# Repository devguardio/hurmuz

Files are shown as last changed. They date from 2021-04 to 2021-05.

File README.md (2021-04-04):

# Hürmüz - an rpi cm4 server board

Hürmüz is a devguard slice server board using the raspberry pi compute module 4 as CPU.

Ethernet is bundled via a KSZ9477 ethernet switch, where each CPU gets its own VLAN.
For recovery and management, USB is connected via an usb switch to an additional managment CPU.

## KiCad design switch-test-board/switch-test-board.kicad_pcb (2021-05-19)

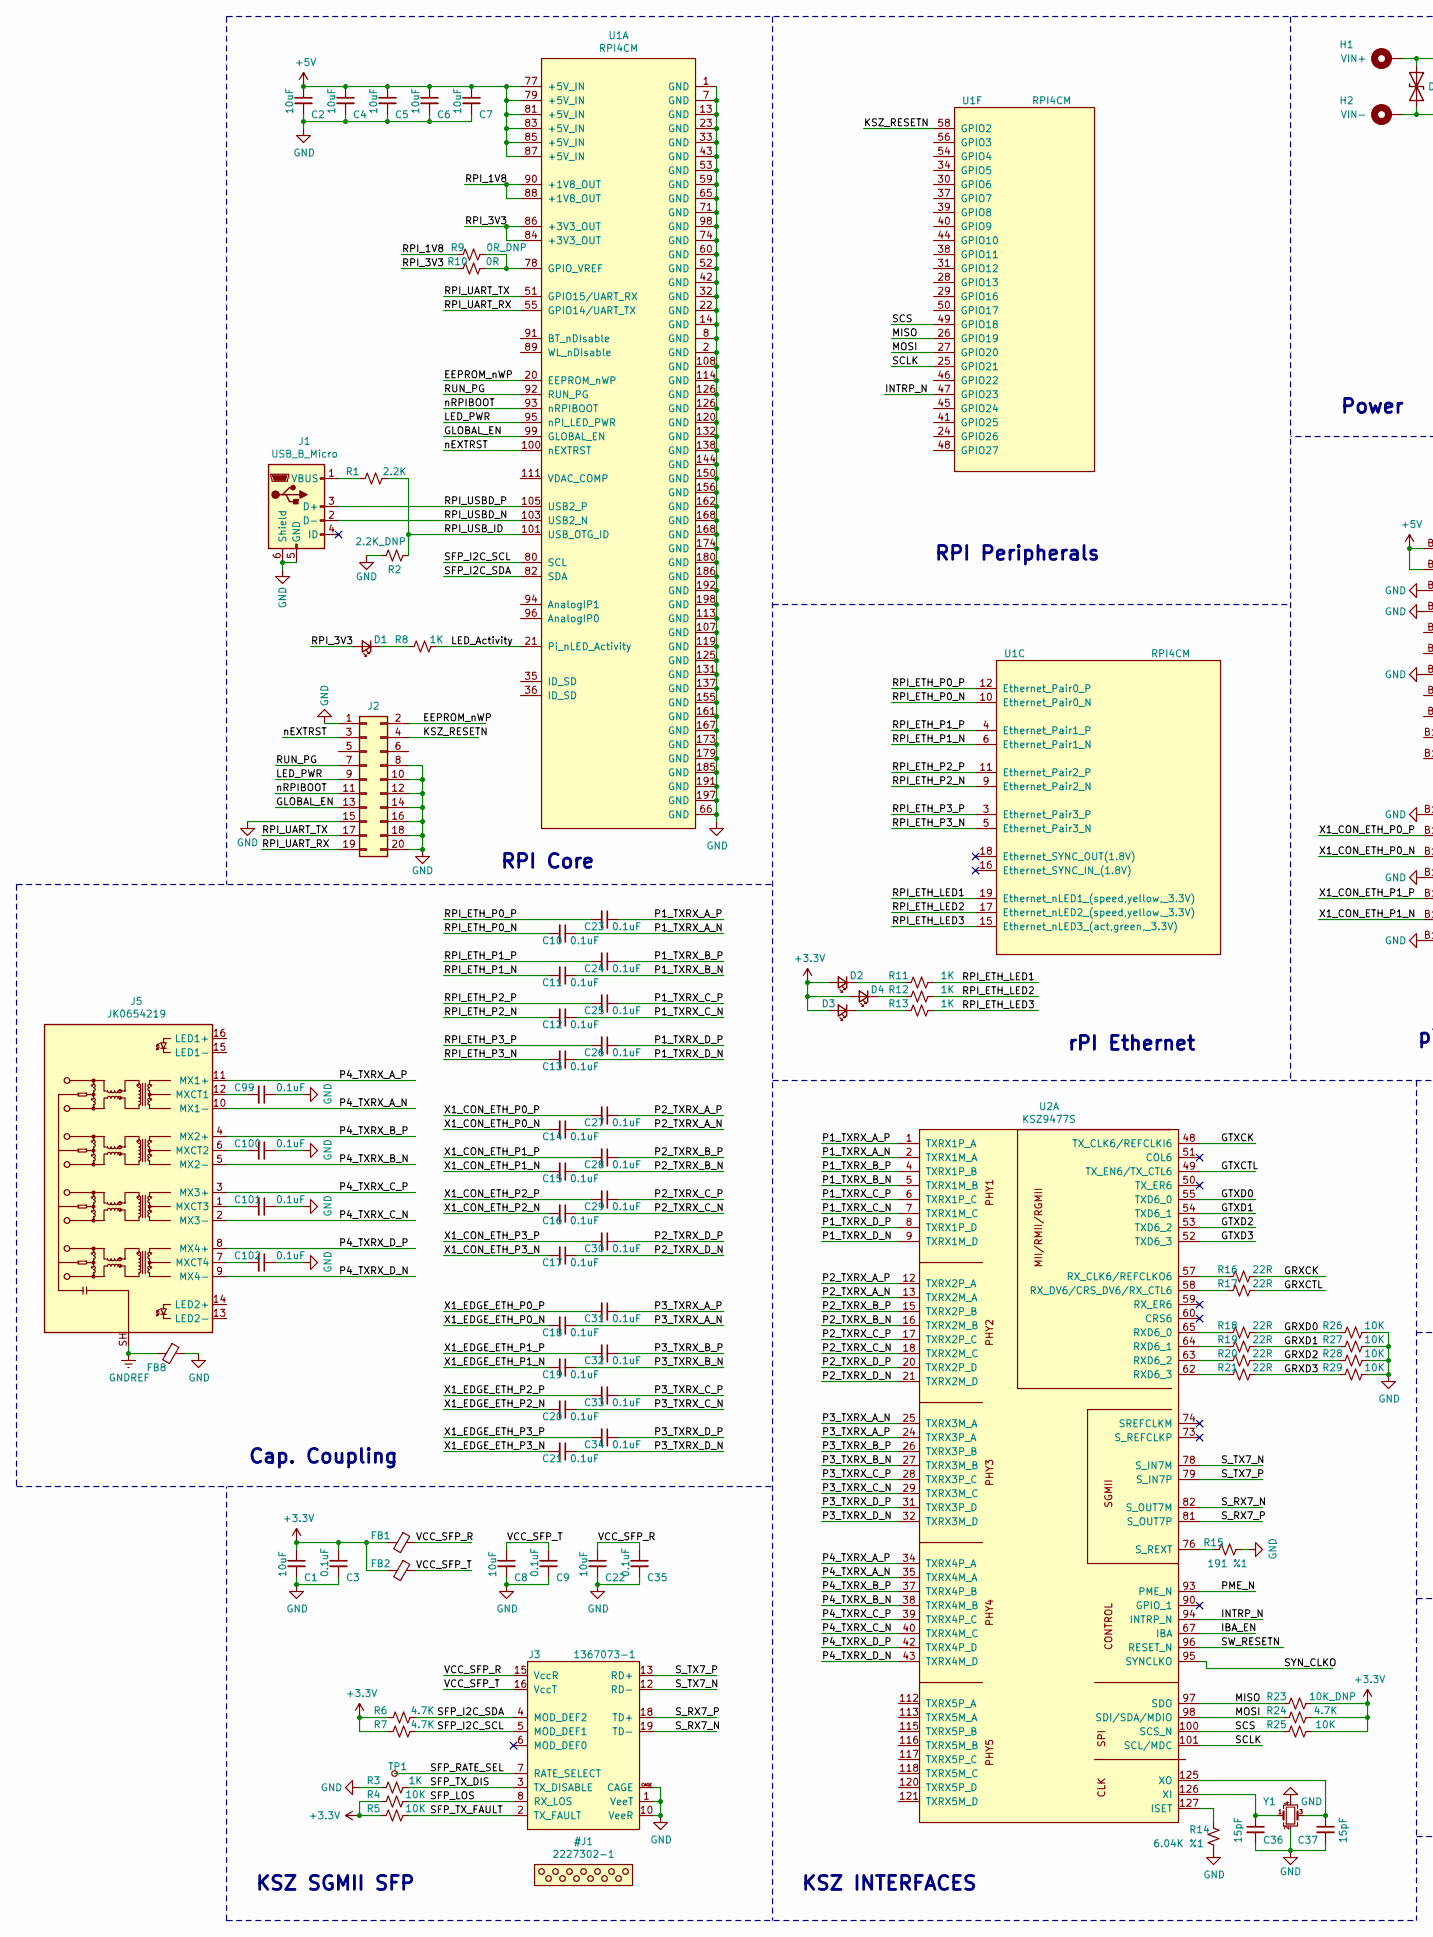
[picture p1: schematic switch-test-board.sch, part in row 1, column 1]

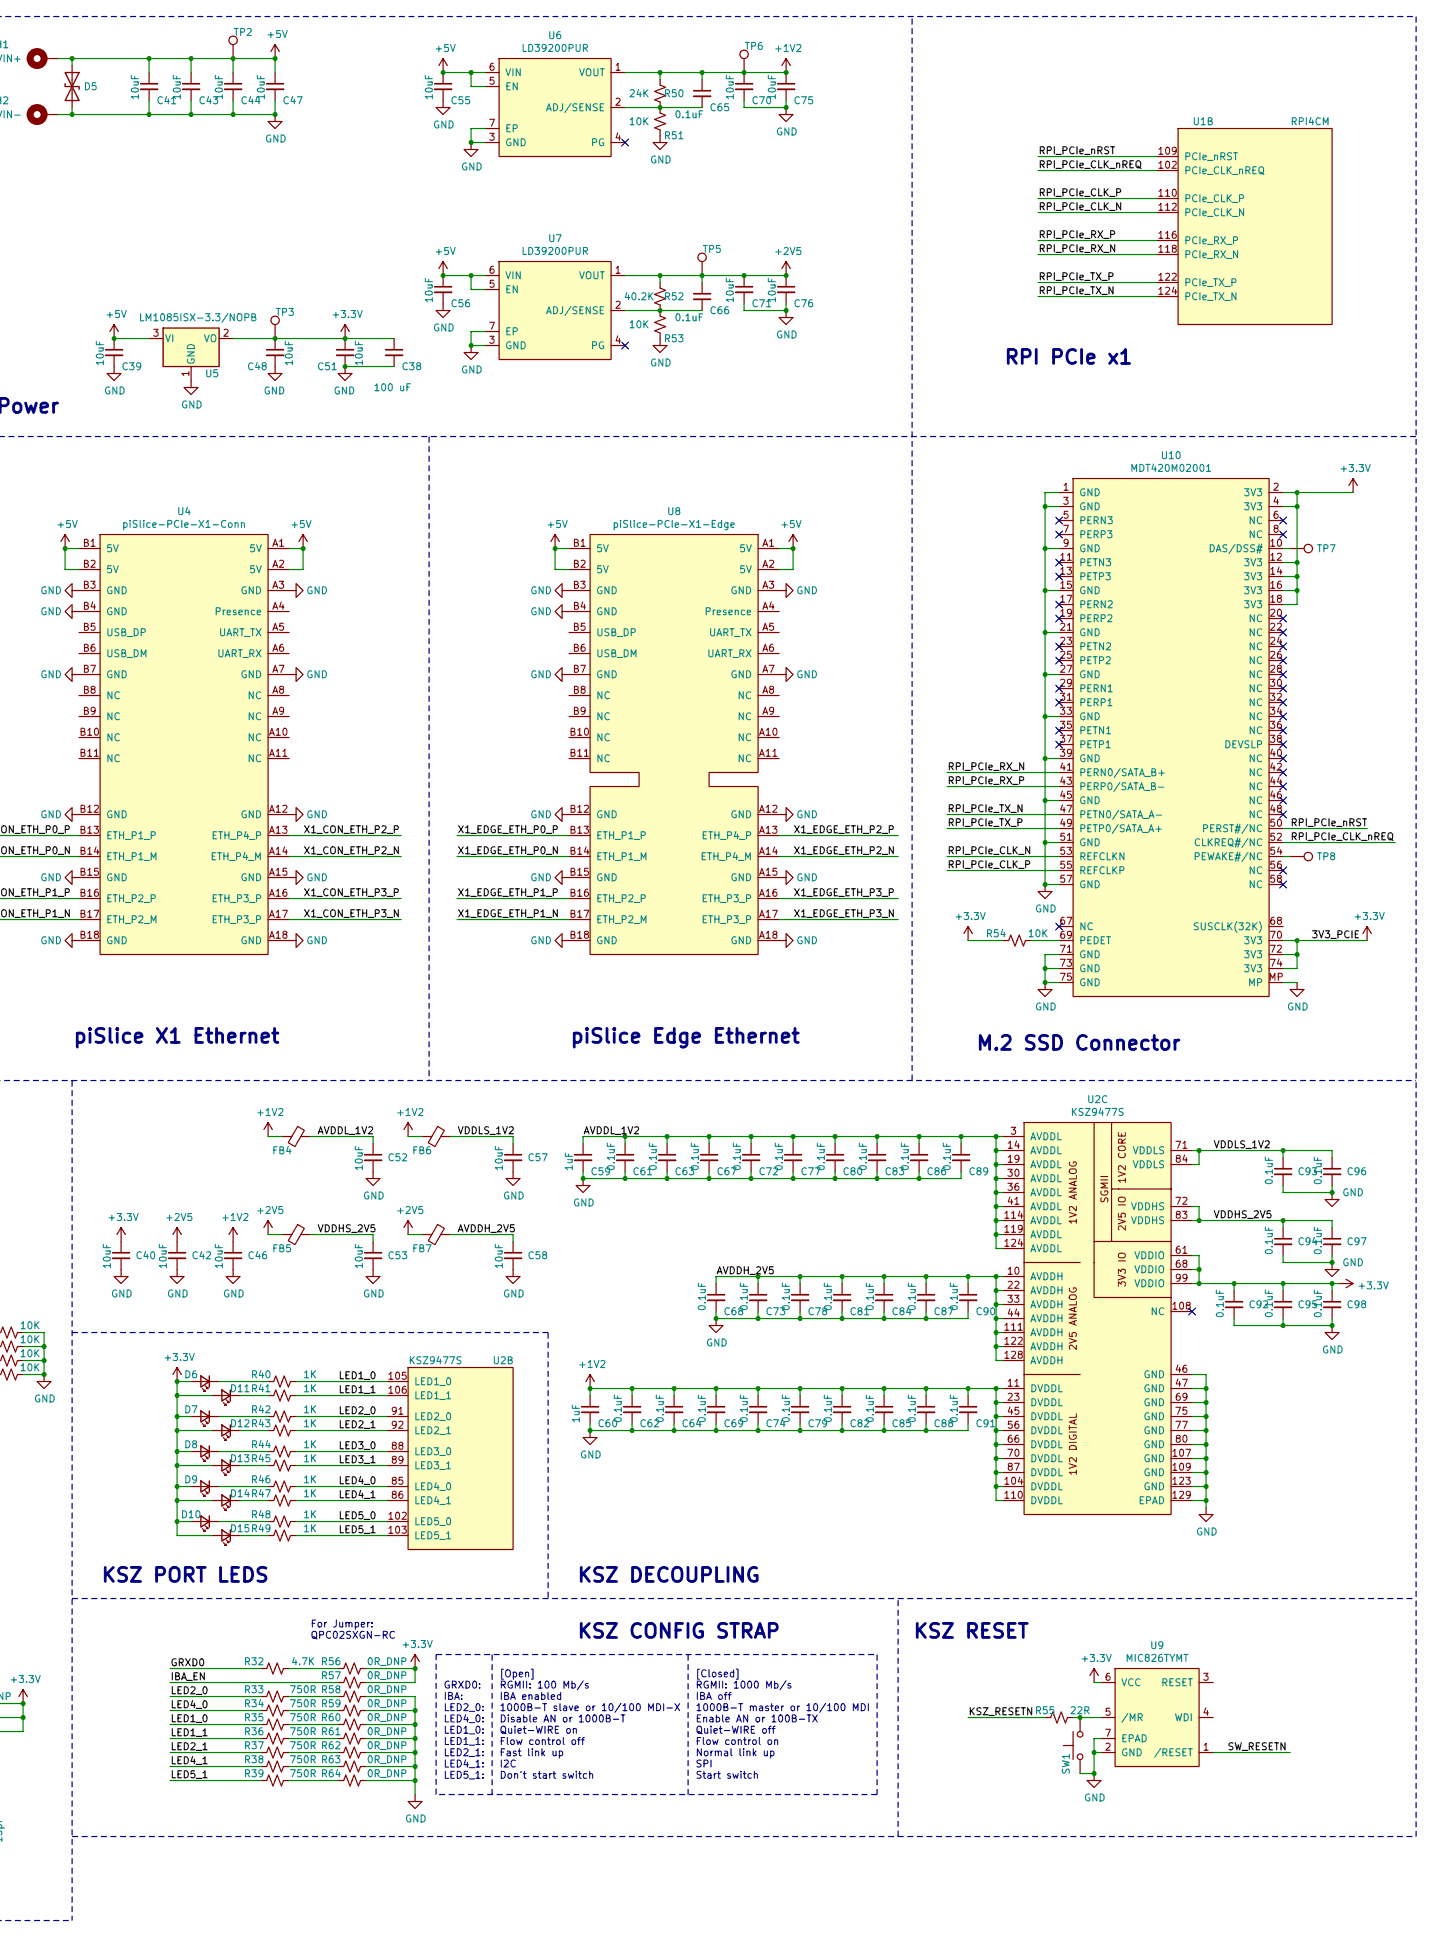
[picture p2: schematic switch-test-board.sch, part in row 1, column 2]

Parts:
C1, C2, C4, C5, C6, C7, C8, C22, C39, C40, C41, C42, C43, C44, C46, C47, C48, C51, C52, C53, C55, C56, C57, C58, C70, C71, C75, C76: 10uF; C_0603_1608Metric
C3, C9, C10, C11, C12, C13, C14, C15, C16, C17, C18, C19, C20, C21, C23, C24, C25, C26, C27, C28, C29, C30, C31, C32, C33, C34, C35, C61, C62, C63, C64, C65, C66, C67, C68, C69, C72, C73, C74, C77, C78, C79, C80, C81, C82, C83, C84, C85, C86, C87, C88, C89, C90, C91, C92, C93, C94, C95, C96, C97, C98, C99, C100, C101, C102: 0.1uF; C_0402_1005Metric
C36, C37: 15pF; C_0402_1005Metric
C38: 100 uF; CP_Elec_5x5.3; Part Number 865080142007
C59, C60: 1uF; C_0402_1005Metric
D1, D2, D4, D11, D12, D13, D14, D15: 150060RS75000; LED_0603_1608Metric
D3, D6, D7, D8, D9, D10: 150060GS75000; LED_0603_1608Metric
D5: SMAJ5.0CA-TR; D_SMA
FB1, FB2, FB4, FB5, FB6, FB7, FB8: BLM18EG221SN1D; ferrite-blm18
H1: VIN+; MountingHole_3.2mm_M3_Pad
H2: VIN-; MountingHole_3.2mm_M3_Pad
J1: USB_B_Micro; USB_Micro-B_GCT_USB3076-30-A
J2: 2011-2X10G00SD025B; PinHeader_2x10_P2.54mm_Vertical
J3: 1367073-1; SFP_with_Cage
J5: JK0654219; RJ45_Pulse_JK0654219NL_Horizontal
R1: 2.2K; R_0402_1005Metric
R2: 2.2K_DNP; R_0402_1005Metric
R3, R8, R11, R12, R13, R40, R41, R42, R43, R44, R45, R46, R47, R48, R49: 1K; R_0402_1005Metric
R4, R5, R25, R26, R27, R28, R29, R51, R53, R54: 10K; R_0402_1005Metric
R6, R7, R24, R32: 4.7K; R_0402_1005Metric
R9, R56, R57, R58, R59, R60, R61, R62, R63, R64: 0R_DNP; R_0402_1005Metric
R10: 0R; R_0402_1005Metric
R14: 6.04K %1; R_0402_1005Metric
R15: 191 %1; R_0402_1005Metric
R16, R17, R18, R19, R20, R21, R55: 22R; R_0402_1005Metric
R23: 10K_DNP; R_0402_1005Metric
R33, R34, R35, R36, R37, R38, R39: 750R; R_0402_1005Metric
R50: 24K; R_0402_1005Metric
R52: 40.2K; R_0402_1005Metric
SW1: PTS645SM43SMTR92 LFS; SW_SPST_PTS645
TP1: TestPoint_Small; TestPoint_Pad_D1.0mm
TP2, TP3, TP5, TP6, TP7, TP8: TestPoint; TestPoint_Pad_D1.0mm
U1: RPI4CM; rpi-cm4
U2: KSZ9477S; 128-TQFP-EP
U4: piSlice-PCIe-X1-Conn; 10018783-10200TLF
U5: LM1085ISX-3.3/NOPB; TO-263-3_TabPin2
U6, U7: LD39200PUR; DFN-6-1EP_3x3mm_P0.95mm_EP1.7x2.6mm
U8: piSlice-PCIe-X1-Edge; piSlice_PCIexpress_x1
U9: MIC826TYMT; MLF-6-1EP_1.6x1.6mm_P0.5mm_EP0.5x1.26mm
U10: MDT420M02001; M.2_Amphenol_MDT_2280
Y1: ABM8G-25.000MHZ-B4Y-T; Crystal_SMD_Abracon_ABM8G-4Pin_3.2x2.5mm

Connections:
+1V2: C46.1, C60.1, C62.1, C64.1, C65.1, C69.1, C70.1, C74.1, C75.1, C79.1, C82.1, C85.1, C88.1, C91.1, FB4.2, FB6.2, R50.2, TP6.1, U2.11 (DVDDL), U2.23 (DVDDL), U2.45 (DVDDL), U2.56 (DVDDL), U2.66 (DVDDL), U2.70 (DVDDL), U2.87 (DVDDL), U2.104 (DVDDL), U2.110 (DVDDL), U6.1 (VOUT)
+2V5: C42.1, C66.1, C71.1, C76.1, FB5.2, FB7.2, R52.2, TP5.1, U7.1 (VOUT)
+3V3: C1.1, C3.1, C38.1, C40.1, C48.1, C51.1, C92.1, C95.1, C98.1, D2.2 (A), D3.2 (A), D4.2 (A), D6.2 (A), D7.2 (A), D8.2 (A), D9.2 (A), D10.2 (A), D11.2 (A), D12.2 (A), D13.2 (A), D14.2 (A), D15.2 (A), FB1.2, FB2.2, R4.1, R5.1, R6.1, R7.1, R23.1, R24.1, R25.1, R54.1, R56.1, R57.1, TP3.1, U2.61 (VDDIO), U2.68 (VDDIO), U2.99 (VDDIO), U5.2 (VO), U9.6 (VCC), U10.2 (3V3), U10.4 (3V3), U10.12 (3V3), U10.14 (3V3), U10.16 (3V3), U10.18 (3V3), U10.70 (3V3), U10.72 (3V3), U10.74 (3V3)
+5V: C2.1, C4.1, C5.1, C6.1, C7.1, C39.1, C41.1, C43.1, C44.1, C47.1, C55.1, C56.1, D5.1 (A1), H1.1, TP2.1, U1.77 (+5V_IN), U1.79 (+5V_IN), U1.81 (+5V_IN), U1.83 (+5V_IN), U1.85 (+5V_IN), U1.87 (+5V_IN), U4.A1 (5V), U4.A2 (5V), U4.B1 (5V), U4.B2 (5V), U5.3 (VI), U6.5 (EN), U6.6 (VIN), U7.5 (EN), U7.6 (VIN), U8.A1 (5V), U8.A2 (5V), U8.B1 (5V), U8.B2 (5V)
/AVDDH_2V5: C58.1, C68.1, C73.1, C78.1, C81.1, C84.1, C87.1, C90.1, FB7.1, U2.10 (AVDDH), U2.22 (AVDDH), U2.33 (AVDDH), U2.44 (AVDDH), U2.111 (AVDDH), U2.122 (AVDDH), U2.128 (AVDDH)
/AVDDL_1V2: C52.1, C59.1, C61.1, C63.1, C67.1, C72.1, C77.1, C80.1, C83.1, C86.1, C89.1, FB4.1, U2.3 (AVDDL), U2.14 (AVDDL), U2.19 (AVDDL), U2.30 (AVDDL), U2.36 (AVDDL), U2.41 (AVDDL), U2.114 (AVDDL), U2.119 (AVDDL), U2.124 (AVDDL)
/EEPROM_nWP: J2.2, U1.20 (EEPROM_nWP)
/GLOBAL_EN: J2.13, U1.99 (GLOBAL_EN)
/GRXCK: R16.2
/GRXCTL: R17.2
/GRXD0: R18.2, R26.1, R32.2
/GRXD1: R19.2, R27.1
/GRXD2: R20.2, R28.1
/GRXD3: R21.2, R29.1
/GTXCK: U2.48 (TX_CLK6/REFCLKI6)
/GTXCTL: U2.49 (TX_EN6/TX_CTL6)
/GTXD0: U2.55 (TXD6_0)
/GTXD1: U2.54 (TXD6_1)
/GTXD2: U2.53 (TXD6_2)
/GTXD3: U2.52 (TXD6_3)
/IBA_EN: R57.2, U2.67 (IBA)
/INTRP_N: U1.47 (GPIO23), U2.94 (INTRP_N)
/KSZ_RESETN: J2.4, R55.1, U1.58 (GPIO2)
/LED1_0: R35.2, R40.1, U2.105 (LED1_0)
/LED1_1: R36.2, R41.1, U2.106 (LED1_1)
/LED2_0: R33.2, R42.1, U2.91 (LED2_0)
/LED2_1: R37.2, R43.1, U2.92 (LED2_1)
/LED3_0: R44.1, U2.88 (LED3_0)
/LED3_1: R45.1, U2.89 (LED3_1)
/LED4_0: R34.2, R46.1, U2.85 (LED4_0)
/LED4_1: R38.2, R47.1, U2.86 (LED4_1)
/LED5_0: R48.1, U2.102 (LED5_0)
/LED5_1: R39.2, R49.1, U2.103 (LED5_1)
/LED_Activity: R8.1, U1.21 (Pi_nLED_Activity)
/LED_PWR: J2.9, U1.95 (nPI_LED_PWR)
/MISO: R23.2, U1.26 (GPIO19), U2.97 (SDO)
/MOSI: R24.2, U1.27 (GPIO20), U2.98 (SDI/SDA/MDIO)
/P1_TXRX_A_N: C10.1, U2.2 (TXRX1M_A)
/P1_TXRX_A_P: C23.1, U2.1 (TXRX1P_A)
/P1_TXRX_B_N: C11.1, U2.5 (TXRX1M_B)
/P1_TXRX_B_P: C24.1, U2.4 (TXRX1P_B)
/P1_TXRX_C_N: C12.1, U2.7 (TXRX1M_C)
/P1_TXRX_C_P: C25.1, U2.6 (TXRX1P_C)
/P1_TXRX_D_N: C13.1, U2.9 (TXRX1M_D)
/P1_TXRX_D_P: C26.1, U2.8 (TXRX1P_D)
/P2_TXRX_A_N: C14.1, U2.13 (TXRX2M_A)
/P2_TXRX_A_P: C27.1, U2.12 (TXRX2P_A)
/P2_TXRX_B_N: C15.1, U2.16 (TXRX2M_B)
/P2_TXRX_B_P: C28.1, U2.15 (TXRX2P_B)
/P2_TXRX_C_N: C16.1, U2.18 (TXRX2M_C)
/P2_TXRX_C_P: C29.1, U2.17 (TXRX2P_C)
/P2_TXRX_D_N: C17.1, U2.21 (TXRX2M_D)
/P2_TXRX_D_P: C30.1, U2.20 (TXRX2P_D)
/P3_TXRX_A_N: C18.1, U2.25 (TXRX3M_A)
/P3_TXRX_A_P: C31.1, U2.24 (TXRX3P_A)
/P3_TXRX_B_N: C19.1, U2.27 (TXRX3M_B)
/P3_TXRX_B_P: C32.1, U2.26 (TXRX3P_B)
/P3_TXRX_C_N: C20.1, U2.29 (TXRX3M_C)
/P3_TXRX_C_P: C33.1, U2.28 (TXRX3P_C)
/P3_TXRX_D_N: C21.1, U2.32 (TXRX3M_D)
/P3_TXRX_D_P: C34.1, U2.31 (TXRX3P_D)
/P4_TXRX_A_N: J5.10 (MX1-), U2.35 (TXRX4M_A)
/P4_TXRX_A_P: J5.11 (MX1+), U2.34 (TXRX4P_A)
/P4_TXRX_B_N: J5.5 (MX2-), U2.38 (TXRX4M_B)
/P4_TXRX_B_P: J5.4 (MX2+), U2.37 (TXRX4P_B)
/P4_TXRX_C_N: J5.2 (MX3-), U2.40 (TXRX4M_C)
/P4_TXRX_C_P: J5.3 (MX3+), U2.39 (TXRX4P_C)
/P4_TXRX_D_N: J5.9 (MX4-), U2.43 (TXRX4M_D)
/P4_TXRX_D_P: J5.8 (MX4+), U2.42 (TXRX4P_D)
/PME_N: U2.93 (PME_N)
/RPI_1V8: R9.1, U1.88 (+1V8_OUT), U1.90 (+1V8_OUT)
/RPI_3V3: D1.2 (A), R10.1, U1.84 (+3V3_OUT), U1.86 (+3V3_OUT)
/RPI_ETH_LED1: R11.1, U1.19 (Ethernet_nLED1_(speed,yellow,_3.3V))
/RPI_ETH_LED2: R12.1, U1.17 (Ethernet_nLED2_(speed,yellow,_3.3V))
/RPI_ETH_LED3: R13.1, U1.15 (Ethernet_nLED3_(act,green,_3.3V))
/RPI_ETH_P0_N: C10.2, U1.10 (Ethernet_Pair0_N)
/RPI_ETH_P0_P: C23.2, U1.12 (Ethernet_Pair0_P)
/RPI_ETH_P1_N: C11.2, U1.6 (Ethernet_Pair1_N)
/RPI_ETH_P1_P: C24.2, U1.4 (Ethernet_Pair1_P)
/RPI_ETH_P2_N: C12.2, U1.9 (Ethernet_Pair2_N)
/RPI_ETH_P2_P: C25.2, U1.11 (Ethernet_Pair2_P)
/RPI_ETH_P3_N: C13.2, U1.5 (Ethernet_Pair3_N)
/RPI_ETH_P3_P: C26.2, U1.3 (Ethernet_Pair3_P)
/RPI_PCIe_CLK_N: U1.112 (PCIe_CLK_N), U10.53 (REFCLKN)
/RPI_PCIe_CLK_P: U1.110 (PCIe_CLK_P), U10.55 (REFCLKP)
/RPI_PCIe_CLK_nREQ: U1.102 (PCIe_CLK_nREQ), U10.52 (CLKREQ#/NC)
/RPI_PCIe_RX_N: U1.118 (PCIe_RX_N), U10.41 (PERN0/SATA_B+)
/RPI_PCIe_RX_P: U1.116 (PCIe_RX_P), U10.43 (PERP0/SATA_B-)
/RPI_PCIe_TX_N: U1.124 (PCIe_TX_N), U10.47 (PETN0/SATA_A-)
/RPI_PCIe_TX_P: U1.122 (PCIe_TX_P), U10.49 (PETP0/SATA_A+)
/RPI_PCIe_nRST: U1.109 (PCIe_nRST), U10.50 (PERST#/NC)
/RPI_UART_RX: J2.19, U1.55 (GPIO14/UART_TX)
/RPI_UART_TX: J2.17, U1.51 (GPIO15/UART_RX)
/RPI_USBD_N: J1.2 (D-), U1.103 (USB2_N)
/RPI_USBD_P: J1.3 (D+), U1.105 (USB2_P)
/RPI_USB_ID: R1.1, R2.2, U1.101 (USB_OTG_ID)
/RUN_PG: J2.7, U1.92 (RUN_PG)
/SCLK: U1.25 (GPIO21), U2.101 (SCL/MDC)
/SCS: R25.2, U1.49 (GPIO18), U2.100 (SCS_N)
/SFP_I2C_SCL: J3.5 (MOD_DEF1), R7.2, U1.80 (SCL)
/SFP_I2C_SDA: J3.4 (MOD_DEF2), R6.2, U1.82 (SDA)
/SFP_LOS: J3.8 (RX_LOS), R4.2
/SFP_RATE_SEL: J3.7 (RATE_SELECT), TP1.1
/SFP_TX_DIS: J3.3 (TX_DISABLE), R3.2
/SFP_TX_FAULT: J3.2 (TX_FAULT), R5.2
/SW_RESETN: U2.96 (RESET_N), U9.1 (/RESET)
/SYN_CLKO: U2.95 (SYNCLKO)
/S_RX7_N: J3.19 (TD-), U2.82 (S_OUT7M)
/S_RX7_P: J3.18 (TD+), U2.81 (S_OUT7P)
/S_TX7_N: J3.12 (RD-), U2.78 (S_IN7M)
/S_TX7_P: J3.13 (RD+), U2.79 (S_IN7P)
/VCC_SFP_R: C22.1, C35.1, FB1.1, J3.15 (VccR)
/VCC_SFP_T: C8.1, C9.1, FB2.1, J3.16 (VccT)
/VDDHS_2V5: C53.1, C94.1, C97.1, FB5.1, U2.72 (VDDHS), U2.83 (VDDHS)
/VDDLS_1V2: C57.1, C93.1, C96.1, FB6.1, U2.71 (VDDLS), U2.84 (VDDLS)
/X1_CON_ETH_P0_N: C14.2, U4.B14 (ETH_P1_M)
/X1_CON_ETH_P0_P: C27.2, U4.B13 (ETH_P1_P)
/X1_CON_ETH_P1_N: C15.2, U4.B17 (ETH_P2_M)
/X1_CON_ETH_P1_P: C28.2, U4.B16 (ETH_P2_P)
/X1_CON_ETH_P2_N: C16.2, U4.A14 (ETH_P4_M)
/X1_CON_ETH_P2_P: C29.2, U4.A13 (ETH_P4_P)
/X1_CON_ETH_P3_N: C17.2, U4.A17 (ETH_P3_P)
/X1_CON_ETH_P3_P: C30.2, U4.A16 (ETH_P3_P)
/X1_EDGE_ETH_P0_N: C18.2, U8.B14 (ETH_P1_M)
/X1_EDGE_ETH_P0_P: C31.2, U8.B13 (ETH_P1_P)
/X1_EDGE_ETH_P1_N: C19.2, U8.B17 (ETH_P2_M)
/X1_EDGE_ETH_P1_P: C32.2, U8.B16 (ETH_P2_P)
/X1_EDGE_ETH_P2_N: C20.2, U8.A14 (ETH_P4_M)
/X1_EDGE_ETH_P2_P: C33.2, U8.A13 (ETH_P4_P)
/X1_EDGE_ETH_P3_N: C21.2, U8.A17 (ETH_P3_P)
/X1_EDGE_ETH_P3_P: C34.2, U8.A16 (ETH_P3_P)
/nEXTRST: J2.3, U1.100 (nEXTRST)
/nRPIBOOT: J2.11, U1.93 (nRPIBOOT)
GND: C1.2, C2.2, C3.2, C4.2, C5.2, C6.2, C7.2, C8.2, C9.2, C22.2, C35.2, C36.2, C37.2, C38.2, C39.2, C40.2, C41.2, C42.2, C43.2, C44.2, C46.2, C47.2, C48.2, C51.2, C52.2, C53.2, C55.2, C56.2, C57.2, C58.2, C59.2, C60.2, C61.2, C62.2, C63.2, C64.2, C67.2, C68.2, C69.2, C70.2, C71.2, C72.2, C73.2, C74.2, C75.2, C76.2, C77.2, C78.2, C79.2, C80.2, C81.2, C82.2, C83.2, C84.2, C85.2, C86.2, C87.2, C88.2, C89.2, C90.2, C91.2, C92.2, C93.2, C94.2, C95.2, C96.2, C97.2, C98.2, C99.1, C100.1, C101.1, C102.1, D5.2 (A2), FB8.1, H2.1, J1.5 (GND), J1.6 (Shield), J2.1, J2.8, J2.10, J2.12, J2.14, J2.15, J2.16, J2.18, J2.20, J3.1 (VeeT), J3.9 (VeeR), J3.10 (VeeR), J3.11 (VeeR), J3.14 (VeeR), J3.17 (VeeT), J3.20 (VeeT), J3.CAGE, R2.1, R3.1, R14.1, R15.2, R26.2, R27.2, R28.2, R29.2, R51.1, R53.1, R58.1, R59.1, R60.1, R61.1, R62.1, R63.1, R64.1, SW1.1, U1.1 (GND), U1.2 (GND), U1.7 (GND), U1.8 (GND), U1.13 (GND), U1.14 (GND), U1.22 (GND), U1.23 (GND), U1.32 (GND), U1.33 (GND), U1.42 (GND), U1.43 (GND), U1.52 (GND), U1.53 (GND), U1.59 (GND), U1.60 (GND), U1.65 (GND), U1.66 (GND), U1.71 (GND), U1.74 (GND), U1.98 (GND), U1.107 (GND), U1.108 (GND), U1.113 (GND), U1.114 (GND), U1.119 (GND), U1.120 (GND), U1.125 (GND), U1.126 (GND), U1.131 (GND), U1.132 (GND), U1.137 (GND), U1.138 (GND), U1.144 (GND), U1.150 (GND), U1.155 (GND), U1.156 (GND), U1.161 (GND), U1.162 (GND), U1.167 (GND), U1.168 (GND), U1.173 (GND), U1.174 (GND), U1.179 (GND), U1.180 (GND), U1.185 (GND), U1.186 (GND), U1.191 (GND), U1.192 (GND), U1.197 (GND), U1.198 (GND), U2.46 (GND), U2.47 (GND), U2.69 (GND), U2.75 (GND), U2.77 (GND), U2.80 (GND), U2.107 (GND), U2.109 (GND), U2.123 (GND), U2.129 (EPAD), U4.A3 (GND), U4.A7 (GND), U4.A12 (GND), U4.A15 (GND), U4.A18 (GND), U4.B3 (GND), U4.B4 (GND), U4.B7 (GND), U4.B12 (GND), U4.B15 (GND), U4.B18 (GND), U5.1 (GND), U6.3 (GND), U6.7 (EP), U7.3 (GND), U7.7 (EP), U8.A3 (GND), U8.A7 (GND), U8.A12 (GND), U8.A15 (GND), U8.A18 (GND), U8.B3 (GND), U8.B4 (GND), U8.B7 (GND), U8.B12 (GND), U8.B15 (GND), U8.B18 (GND), U9.2 (GND), U9.7 (EPAD), U10.1 (GND), U10.3 (GND), U10.9 (GND), U10.15 (GND), U10.21 (GND), U10.27 (GND), U10.33 (GND), U10.39 (GND), U10.45 (GND), U10.51 (GND), U10.57 (GND), U10.71 (GND), U10.73 (GND), U10.75 (GND), U10.MP, Y1.2, Y1.4
GNDREF: FB8.2, J5.SH
unnamed: C36.1, U2.126 (XI), Y1.1
unnamed: C37.1, U2.125 (XO), Y1.3
unnamed: C65.2, R50.1, R51.2, U6.2 (ADJ/SENSE)
unnamed: C66.2, R52.1, R53.2, U7.2 (ADJ/SENSE)
unnamed: C99.2, J5.12 (MXCT1)
unnamed: C100.2, J5.6 (MXCT2)
unnamed: C101.2, J5.1 (MXCT3)
unnamed: C102.2, J5.7 (MXCT4)
unnamed: D1.1 (K), R8.2
unnamed: D2.1 (K), R11.2
unnamed: D3.1 (K), R13.2
unnamed: D4.1 (K), R12.2
unnamed: D6.1 (K), R40.2
unnamed: D7.1 (K), R42.2
unnamed: D8.1 (K), R44.2
unnamed: D9.1 (K), R46.2
unnamed: D10.1 (K), R48.2
unnamed: D11.1 (K), R41.2
unnamed: D12.1 (K), R43.2
unnamed: D13.1 (K), R45.2
unnamed: D14.1 (K), R47.2
unnamed: D15.1 (K), R49.2
unnamed: J1.1 (VBUS), R1.2
unnamed: R9.2, R10.2, U1.78 (GPIO_VREF)
unnamed: R14.2, U2.127 (ISET)
unnamed: R15.1, U2.76 (S_REXT)
unnamed: R16.1, U2.57 (RX_CLK6/REFCLKO6)
unnamed: R17.1, U2.58 (RX_DV6/CRS_DV6/RX_CTL6)
unnamed: R18.1, U2.65 (RXD6_0)
unnamed: R19.1, U2.64 (RXD6_1)
unnamed: R20.1, U2.63 (RXD6_2)
unnamed: R21.1, U2.62 (RXD6_3)
unnamed: R32.1, R56.2
unnamed: R33.1, R58.2
unnamed: R34.1, R59.2
unnamed: R35.1, R60.2
unnamed: R36.1, R61.2
unnamed: R37.1, R62.2
unnamed: R38.1, R63.2
unnamed: R39.1, R64.2
unnamed: R54.2, U10.69 (PEDET)
unnamed: R55.2, SW1.2, U9.5 (/MR)
unnamed: TP7.1, U10.10 (DAS/DSS#)
unnamed: TP8.1, U10.54 (PEWAKE#/NC)

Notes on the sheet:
For Jumper: QPC02SXGN-RC
GRXD0: IBA: LED2_0: LED4_0: LED1_0: LED1_1: LED2_1: LED4_1: LED5_1:
[Closed] RGMII: 1000 Mb/s IBA off 1000B-T master or 10/100 MDI Enable AN or 100B-TX Quiet-WIRE off Flow control on Normal link up SPI Start switch
[Open] RGMII: 100 Mb/s IBA enabled 1000B-T slave or 10/100 MDI-X Disable AN or 1000B-T Quiet-WIRE on Flow control off Fast link up I2C Don't start switch
KSZ CONFIG STRAP
KSZ RESET
KSZ DECOUPLING
KSZ PORT LEDS
KSZ INTERFACES
KSZ SGMII SFP
M.2 SSD Connector
piSlice Edge Ethernet
piSlice X1 Ethernet
Power
RPI PCIe x1
Cap. Coupling
rPI Ethernet
RPI Peripherals
RPI Core

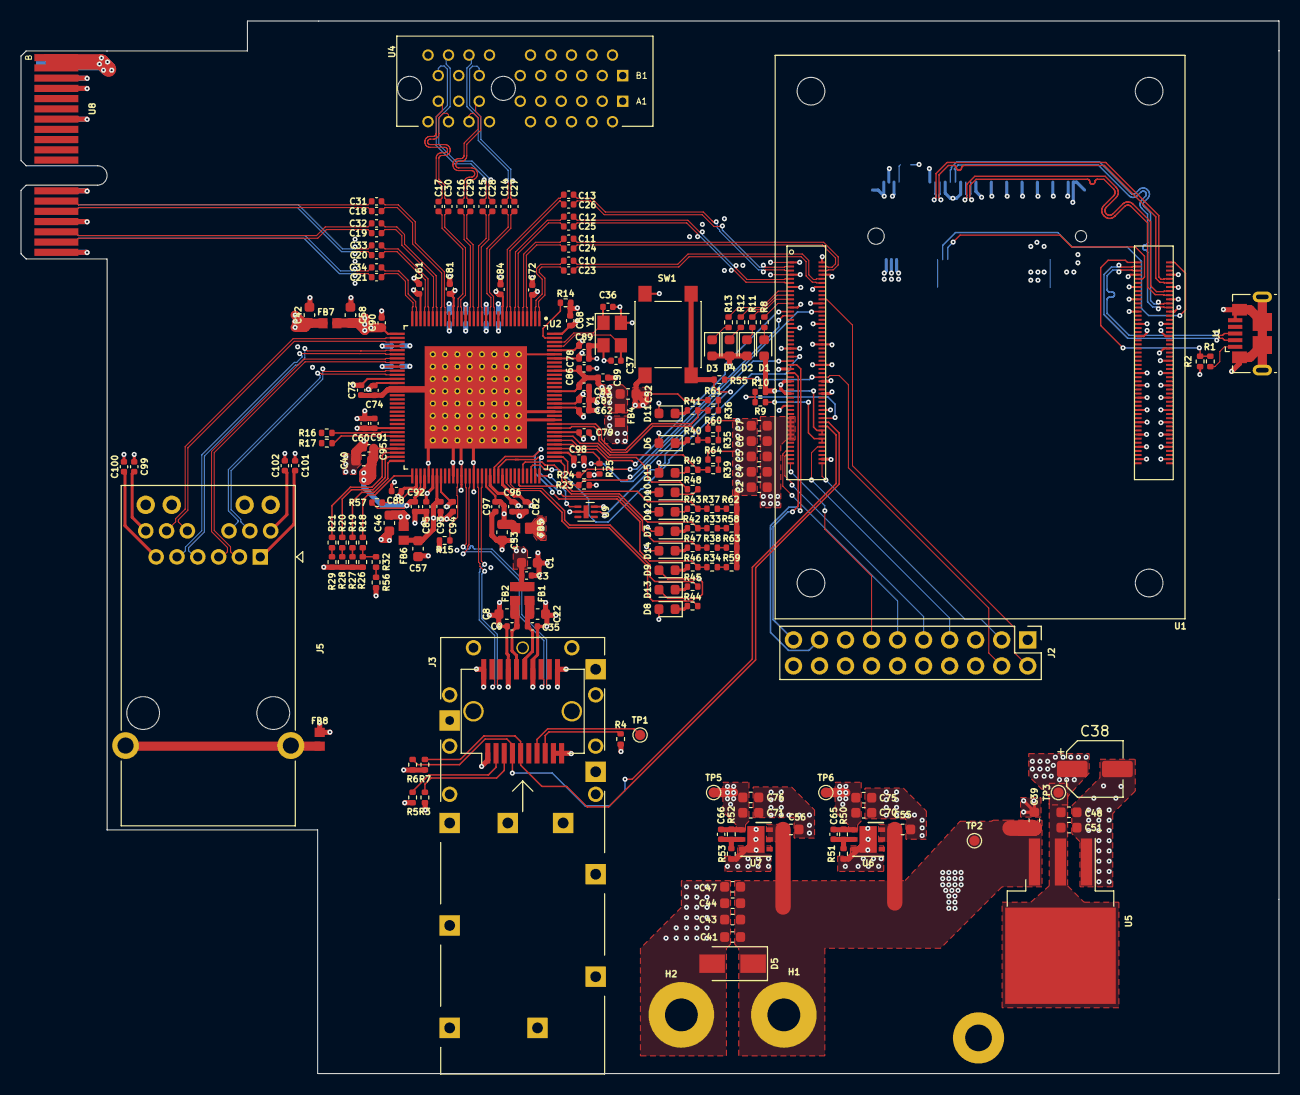
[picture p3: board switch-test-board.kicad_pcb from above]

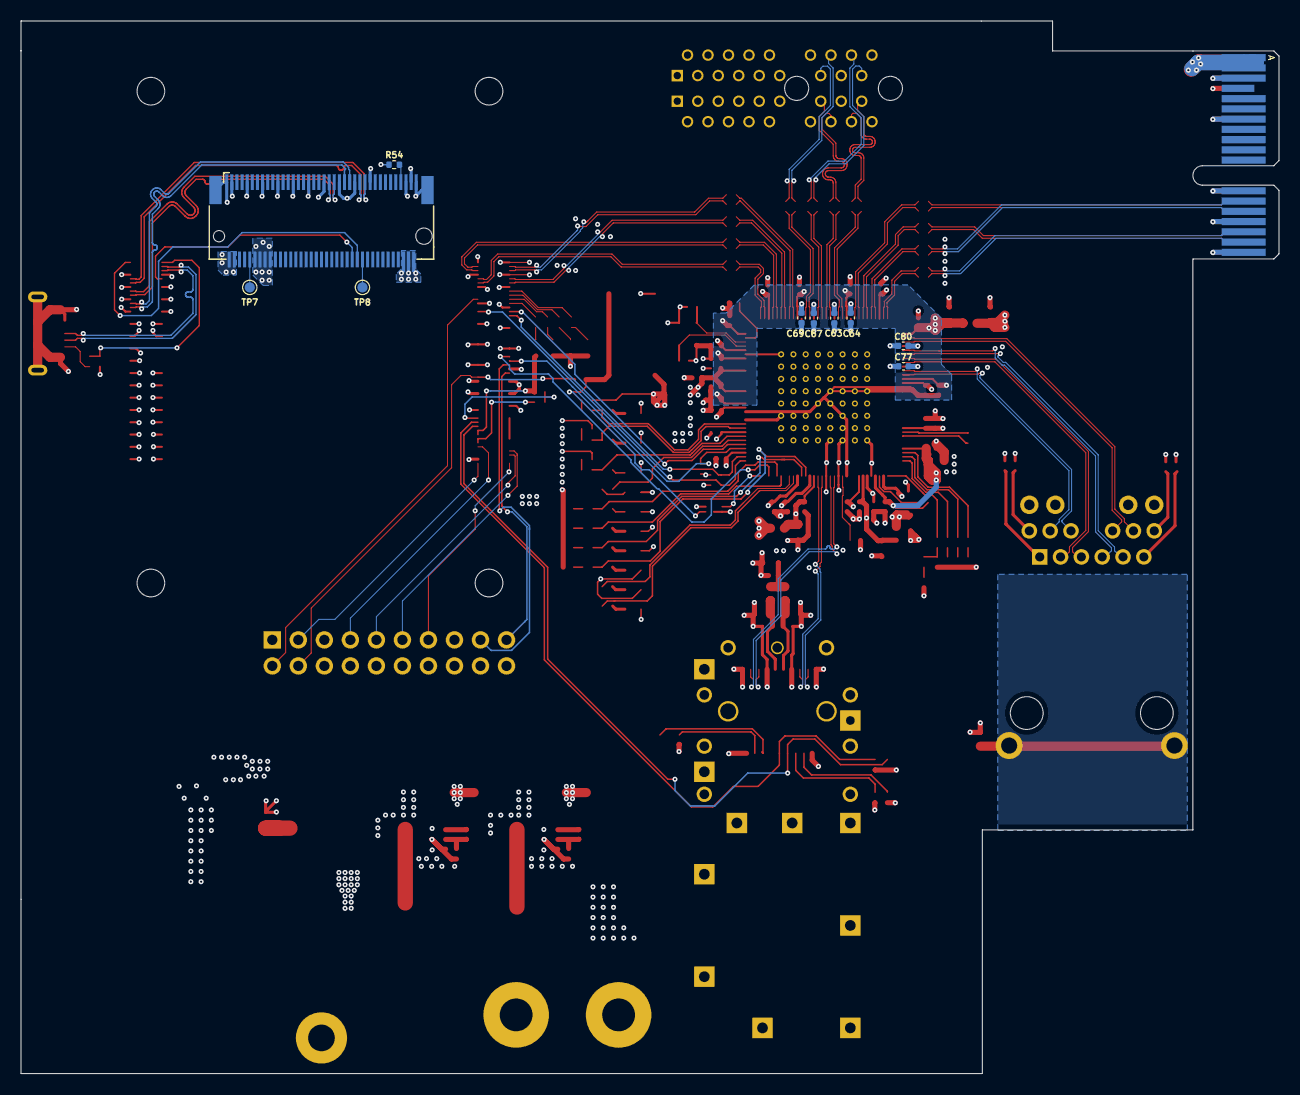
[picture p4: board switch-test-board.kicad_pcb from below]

Board: 4 copper layers, 122.8 x 102.7 mm, 205 parts (10 on the bottom side), 169 nets.

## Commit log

2021-03-24 Updated Sch.
    [switch-test-board.kicad_pcb, switch-test-board.sch]
2021-03-24 Sch. update.
    [switch-test-board.sch]
2021-03-24 Added KSZ Switch IC Decoupling and Port Leds.
    [switch-test-board.kicad_pcb, switch-test-board.sch]
2021-03-28 Updated Schematic.
    [switch-test-board.kicad_pcb, switch-test-board.sch]
2021-03-28 Added PCIe x1 to NVMe adapter.
    [switch-test-board.sch]
2021-03-29 Schematic completed.
    [switch-test-board.sch]
2021-03-30 PCB Design planning.
    [switch-test-board.kicad_pcb, switch-test-board.sch]
2021-04-04 PCB Design Updated.
    [switch-test-board.kicad_pcb, switch-test-board.sch]
2021-04-04 Completed routing eth. interfaces.
    [switch-test-board.kicad_pcb, switch-test-board.sch]
2021-04-25 PCB updated.
    [switch-test-board.kicad_pcb, switch-test-board.sch]
2021-05-19 PCB Design Completed.
    [switch-test-board.kicad_pcb, switch-test-board.sch]
